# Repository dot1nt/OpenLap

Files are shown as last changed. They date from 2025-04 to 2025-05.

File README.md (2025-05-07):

<br>
<div align=center>
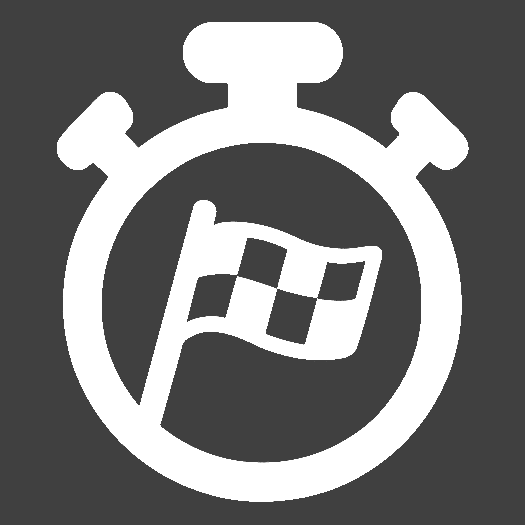
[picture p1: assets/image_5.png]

<h1>OpenLap</h1> 
<strong>A single pilot ESP32 / RX5808 based FPV laptimer</strong>
</div>
<br>

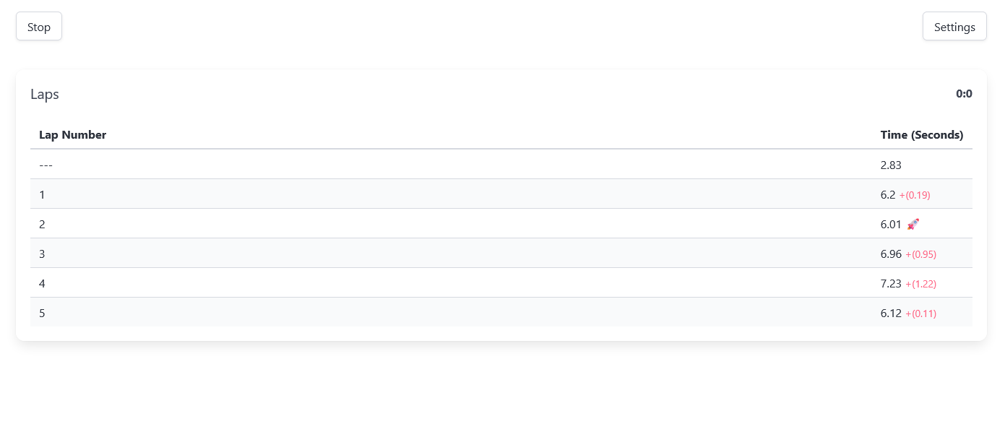
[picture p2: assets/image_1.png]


# Build

## Hardware  
You need an RX5808 with [SPI Mod](https://sheaivey.github.io/rx5808-pro-diversity/docs/rx5808-spi-mod.html). Desolder the antenna and connect the receiver like this:  
- **CH1** → pin `D23` (MOSI)
- **CH2** → pin `D22`
- **CH3** → pin `D18` (SCK)
- **RSSI** → pin `D33`

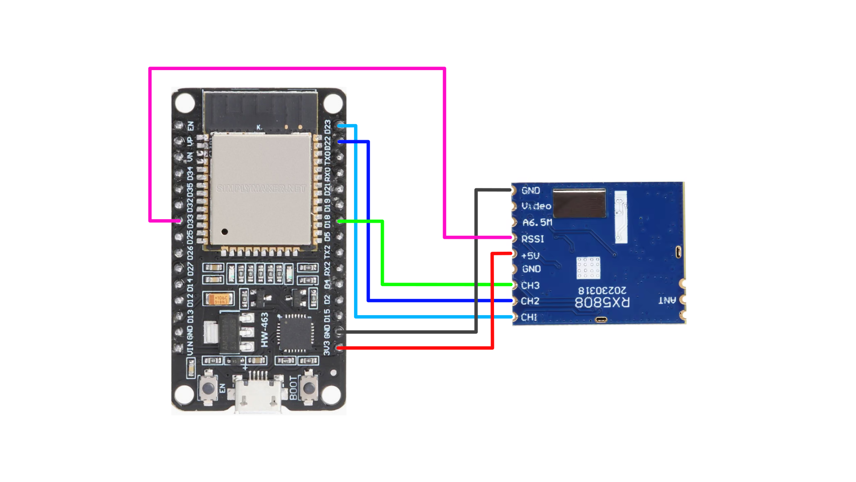
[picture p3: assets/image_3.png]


## Firmware  
You’ll need [VS Code](https://code.visualstudio.com/) and the PlatformIO extension.
Once you've downloaded the code (click the green 'Code' button at the top and select 'Download ZIP'), open the project and hit the upload arrow at the bottom to flash the firmware.  
The web page has to be uploaded separately — open PlatformIO (left sidebar) and click "Upload Filesystem Image".

## Configuration  
Settings are in `src/config.h`.
If you are not using the standard ESP32 developement board, you can change the board type in the `platformio.ini` file.
Here are the board types supported by platformio that might work: https://docs.platformio.org/en/latest/boards/index.html#espressif-32

### Battery Monitoring

The ESP32 has a 3.3V input voltage limit, so it's not safe to connect the battery directly to read the voltage. 
To bring the voltage down to a safe level, you can use a [voltage divider](https://en.wikipedia.org/wiki/Voltage_divider) consisting of two resistors to step down the voltage before it reaches the ESP32.

You can configure the resistor values for the voltage divider by adjusting `R1` and `R2` in `src/config.h`.
You can use this [calculator](https://ohmslawcalculator.com/voltage-divider-calculator) to select suitable resistor values.
For a 4s battery, safe resistor values could be `100kOhm` for R1 and `20kOhm` for R2.

To enable battery monitoring:
1. Set `ENABLE_BATTERY_MONITORING` to `true`.
2. Set the pin where the voltage divider is connected by modifying `BATTERY_PIN` (this needs to be an analog input).

Additionally, you can set a minimum voltage threshold in the web page settings to receive a notification when the battery voltage drops below this level.

# Usage  
The ESP32 opens a Wi-Fi AP you can connect to. Wi-Fi name and password can be changed in `src/config.h`. The default password is `Laptimer`.
To access the app, open `http://192.168.4.1` in your browser.  
Pick your band and channel in the settings, save it, then hold your drone in the worst signal spot at the gate and click "Calibrate".
Set lap number to `0` if you want the race to run forever.

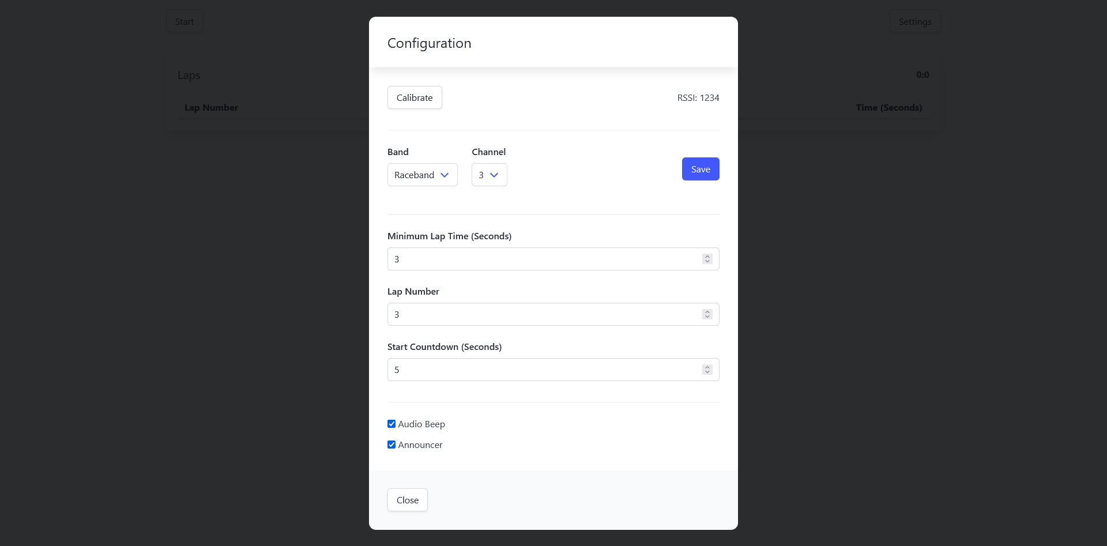
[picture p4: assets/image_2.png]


# Case  
The case files are inside the `cad` folder. Mount the ESP32 with thick double sided tape.



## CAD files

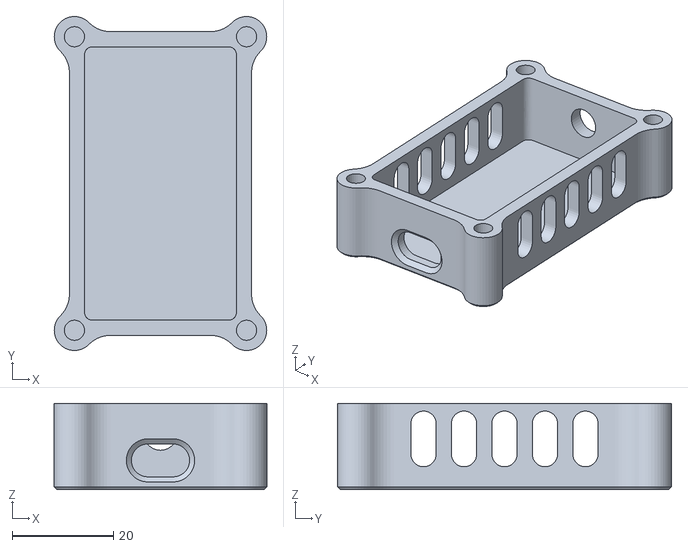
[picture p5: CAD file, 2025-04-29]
cad/bottom_heat_press_inserts.stl
42.0 x 66.0 x 17.0

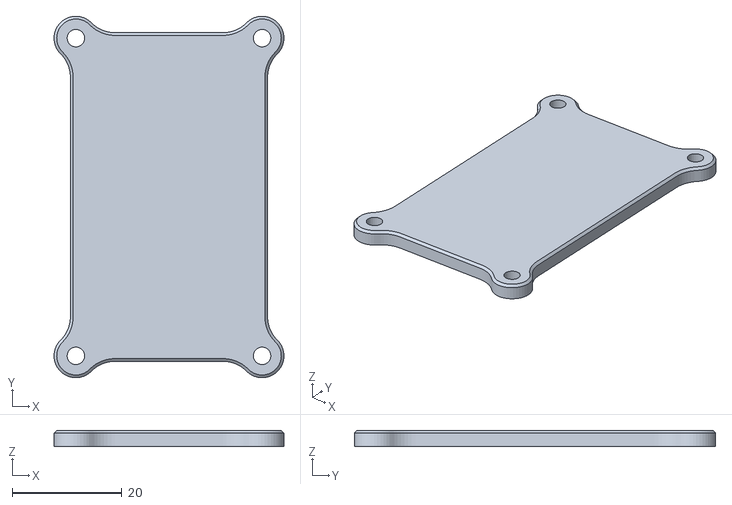
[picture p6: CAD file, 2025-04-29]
cad/top.stl
42.0 x 66.0 x 3.00

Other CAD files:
cad/bottom.stl

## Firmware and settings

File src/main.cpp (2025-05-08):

#include <Arduino.h>
#include <AsyncTCP.h>
#include <ESPAsyncWebServer.h>
#include <LittleFS.h>
#include <WiFi.h>

#include "config.h"
#include "filter.h"
#include "peak_detector.h"
#include "race_manager.h"
#include "rx5808.h"
#include "web.h"

Config config;
Rx5808 rx(Config::RSSI_PIN, Config::CH2_PIN);
PeakDetector peakDetector;
Filter filter(Config::RX_FILTER_SIZE);
RaceManager raceManager;

AsyncWebServer server(80);
WebSocketHandler webSocketHandler;
QueueHandle_t xWebSocketMessageQueue;
unsigned long lastRssiWebSocketMessage;
unsigned long lastBatteryWebSocketMessage;

void calibrateReceiver() {
  int sum = 0;

  for (int i = 0; i < Config::RX_CALIBRATION_SAMPLES; i++) {
    sum += rx.readRssi();
    delay(Config::RX_CALIBRATION_INTERVAL);
  }

  int average = sum / Config::RX_CALIBRATION_SAMPLES;

  peakDetector.setThreshold(average);
  config.setThreshold(average);
}

void setReceiverFrequency(uint16_t frequency) {
  rx.setFrequency(frequency);
  config.setFrequency(frequency);
}

void sendStateToWebsocket() {
  int raceState = raceManager.getRaceState();
  const std::vector<unsigned long> &lapTimes = raceManager.getLapTimes();
  uint16_t frequency = config.getFrequency();

  webSocketHandler.sendState(raceState, lapTimes, frequency);
}

void vTask(void *pvParameters) {
  for (;;) {
    vTaskDelay(pdMS_TO_TICKS(Config::RX_UPDATE_INTERVAL));

    int rssi = rx.readRssi();
    int filteredRssi = filter.process(rssi);

    if (millis() - lastRssiWebSocketMessage > Config::RSSI_UPDATE_INTERVAL) {
      lastRssiWebSocketMessage = millis();
      webSocketHandler.sendRssiData(filteredRssi);
    }

    if (millis() - lastBatteryWebSocketMessage > Config::BATTERY_UPDATE_INTERVAL && Config::ENABLE_BATTERY_MONITORING) {
      lastBatteryWebSocketMessage = millis();
      int batteryVoltage = analogRead(Config::BATTERY_PIN);
      int batteryVoltageScaled = batteryVoltage * 3.3 / 4095 * (Config::R1 + Config::R2) / Config::R2 * 1000;

      webSocketHandler.sendBatteryData(batteryVoltageScaled);
    }

    std::optional<PeakDetector::TimeValue> peak = peakDetector.addData(filteredRssi, millis());

    if (peak.has_value()) {
      PeakDetector::TimeValue peakData = peak.value();

      if (raceManager.addLap(peakData.time)) {
        sendStateToWebsocket();
      }
    }
  }
}

void vHandleWebSocketMessages(void *pvParameters) {
  for (;;) {
    vTaskDelay(pdMS_TO_TICKS(Config::RX_UPDATE_INTERVAL));

    WebSocketHandler::WebSocketMessage msg;
    if (xQueueReceive(xWebSocketMessageQueue, &msg, portMAX_DELAY) == pdTRUE) {
      if (std::holds_alternative<WebSocketHandler::Command>(msg)) {
        WebSocketHandler::Command command = std::get<WebSocketHandler::Command>(msg);

        switch (command) {
          case WebSocketHandler::Command::CALIBRATE_RECEIVER:
            calibrateReceiver();
            break;

          case WebSocketHandler::Command::GET_STATE:
            sendStateToWebsocket();
            break;

          case WebSocketHandler::Command::STOP_RACE:
            raceManager.stopRace();
            break;

          default:
            break;
        }

      } else if (std::holds_alternative<WebSocketHandler::FrequencyChange>(msg)) {
        uint16_t frequency = std::get<WebSocketHandler::FrequencyChange>(msg).frequency;
        setReceiverFrequency(frequency);
        sendStateToWebsocket();

      } else if (std::holds_alternative<WebSocketHandler::RaceStart>(msg)) {
        WebSocketHandler::RaceStart raceInfo = std::get<WebSocketHandler::RaceStart>(msg);
        raceManager.startRace(raceInfo.lapNumber, raceInfo.maxRaceStartCountdown, raceInfo.minLapTime);
        sendStateToWebsocket();
      }
    }
  }
}

void setupServer() {
  if (!WiFi.softAP(Config::SSID, Config::WIFI_PASSWORD)) {
    Serial.println("Failed to start WiFi AP");
    return;
  }

  if (!LittleFS.begin(true)) {
    Serial.println("LittleFS Mount Failed");
    return;
  }

  server.on("/", HTTP_GET, [](AsyncWebServerRequest *request) {
    request->send(LittleFS, "/index.html", "text/html");
  });
  server.serveStatic("/", LittleFS, "/");

  server.addHandler(webSocketHandler.getSocket());

  server.begin();
}

void setup() {
  Serial.begin(115200);

  config.loadEEPROMConfig();

  setupServer();

  xWebSocketMessageQueue = xQueueCreate(10, sizeof(WebSocketHandler::WebSocketMessage));
  webSocketHandler.addListener(xWebSocketMessageQueue);
  webSocketHandler.begin();

  rx.init();
  rx.setFrequency(config.getFrequency());

  peakDetector.setThreshold(config.getThreshold());

  raceManager.onRaceStart(sendStateToWebsocket);
  raceManager.onRaceEnd(sendStateToWebsocket);
  raceManager.onRaceFalseStart(sendStateToWebsocket);
  raceManager.begin();

  xTaskCreate(vHandleWebSocketMessages, "WebSocketMessages", 2048, nullptr, 2, nullptr);
  xTaskCreate(vTask, "vTask", 4096, nullptr, 2, nullptr);
}

void loop() {}

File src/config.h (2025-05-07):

#pragma once

#include <Arduino.h>

#include <memory>

class Config {
 public:
  // WiFi network credentials
  static constexpr const char *SSID = "Laptimer";
  static constexpr const char *WIFI_PASSWORD = "Laptimer";

  static constexpr uint8_t RSSI_PIN = 33;  // RSSI output pin
  static constexpr uint8_t CH2_PIN = 22;   // Chip select pin (CH2 on the rx5808)

  static constexpr bool ENABLE_BATTERY_MONITORING = false;       // Set this to true to enable sending battery info to the client
  static constexpr uint8_t BATTERY_PIN = 35;                     // Input pin for reading battery voltage
  static constexpr int R1 = 100000;                              // Resistor 1 (pin to battery) resistance in ohm
  static constexpr int R2 = 20000;                               // Resistor 2 (pin to GND) resistance in ohm
  static constexpr unsigned long BATTERY_UPDATE_INTERVAL = 1000; // Interval to send battery voltage to clients in milliseconds

  static constexpr unsigned long RX_UPDATE_INTERVAL = 5;      // Receiver polling interval in milliseconds
  static constexpr unsigned long RSSI_UPDATE_INTERVAL = 200;  // Interval to send RSSI data to clients in milliseconds

  static constexpr size_t RX_FILTER_SIZE = 10;  // Number of samples to average for smoothing RSSI readings

  static constexpr size_t RX_CALIBRATION_SAMPLES = 10;          // Number of samples to average during receiver calibration
  static constexpr unsigned long RX_CALIBRATION_INTERVAL = 10;  // Delay between calibration samples in milliseconds

  Config() = default;

  void setFrequency(uint16_t frequency);
  uint16_t getFrequency();

  void setThreshold(int threshold);
  int getThreshold();

  void loadEEPROMConfig();

 private:
  static constexpr uint16_t DEFAULT_FREQUENCY = 5865;  // A1
  static constexpr int DEFAULT_THRESHOLD = 1000;

  struct UserConfig {
    uint16_t frequency = DEFAULT_FREQUENCY;
    int threshold = DEFAULT_THRESHOLD;
  };

  UserConfig m_userConfig;

  void saveEEPROMConfig();

  static bool frequencyValid(uint16_t frequency);
  static bool thresholdValid(int threshold);
};

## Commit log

2025-05-07 Add battery monitoring (web page)
2025-05-07 Add battery monitoring
2025-05-08 Show race end modal on stop button
